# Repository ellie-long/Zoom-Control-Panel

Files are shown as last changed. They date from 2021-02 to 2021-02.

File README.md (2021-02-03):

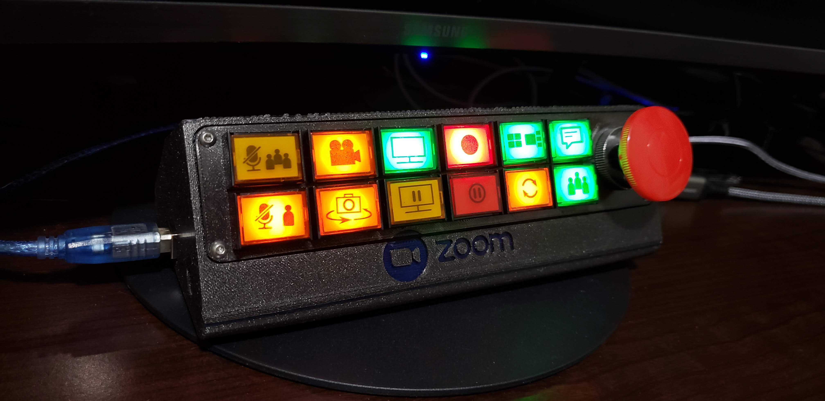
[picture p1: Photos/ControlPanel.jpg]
Zoom Control Panel

# Zoom Control Panel
 A push-button control panel for Zoom
 
 This repo contains files for building a push-button control panel for Zoom. It was made using Windows short cuts, but could easily be modified for Mac instead. 
 
 There are four major components to this build:
 * A 3D-printed case
 * Optional: Printing and installing button icons
 * Wiring buttons and Arduino Mega 2560
 * Programming Arduino
 
# Parts List
 In order to build this project, you will need:
 * Access to a 3D printer
 * An Arduino Mega 2560 board
   * An optional spare Arduino for uploading HoodLoader2 (https://github.com/NicoHood/HoodLoader2), which is required to use the Mega2560 as a keyboard input 
 * A 2560 Prototype Circuit Breakout Board PCB
 * Enough 2.54mm male header pins to mount the breakout board PCB to the Arduino
   * I used the full groupings of 1x10, 5 1x8, 2 1x18 in mine for stability, though you could get away with just the two 1x18 or a single 2x18
 * 12 rectangular LA128A push buttons rated at 12V
   * (If you find 5V ones, even better, though the 12V ones work just fine.) 
   * This design was made with the 16mm rectangular ones in mind, though others should work as well -- however, the button icons may need to be scaled to fit other sizes
   * As designed, I used the following, though you can update it to your own preference:
     * 4 Orange Latching Switches
     * 2 Orange Momentary Switches
     * 2 Red Latching Switches
     * 3 Green Momentary Switches
     * 1 Green Latching Switch
 * A red mushroom LAY37-11ZS push button
 * 13 10k Ohm Resistors
 * Various hook-up wires, preferably in multiple colors to keep track of wires
 * Optional: Glossy transparent printable sticker 'paper' for icons
 * 8 M3 nuts
 * 8 small M3 screws
 * Optional long USB-A or USB extension cable to connect panel to the computer
 * Small flathead screwdriver

# 3D Printed Case
 There are two files that need to be 3D printed to create the case. They are found in 3D Print/To Print, which contains these \*.stl files for the button panel and the main body.
 These files have been designed to not require supports when printing, though you may want to use a brim. I printed it on a Prusa Mk3S+ using PETG with 0.20mm layer heights.
 
 Once printed, M3 nuts can be pushed into place for each of the 8 screw-holes. If they fall out, you can use a small amount of superglue around the edge to hold them into place.
 
 The CAD design was built in FreeCAD, and the original FreeCAD files are included under 3D Print/CAD Files if you wish to modify them.

# Printing and Installing Button Icons
 * In the Icons folder you can find a \*.svg and \*.pdf of icons that can be printed onto transparent sticker 'paper', carefully cut out, and adhered to the push buttons.
 * Using a small flathead screwdriver, you can carefully remove the colored transparent window from the push buttons. 
 * Behind it sits a white rectangle, followed by a white piece of plastic that connects the button mechanism to the front part that is pressed. 
 * Carefully place the sticker onto the white rectangle, then reassemble the button
   * Make sure to check that the button pushes and released properly. If not, the button may have been inserted backwards. 
     * Try to keep track of which buttons each parts came from, as mixing them can lead to buttons sticking.
 * As printed, the buttons are:
   * Mute Me | Video | Share Screen | Record | Gallery/Speaker View | Chat
   * Mute All | Camera | Pause Screen Share | Pause Recording | Reset | Participants

# Wiring and Assembly
* Before spending a lot of time wiring, first make sure to install HoodLoader2 on your Arduino so that you can use it as a keyboard. Follow the Hardware and Software Installations in their wiki before going further: https://github.com/NicoHood/HoodLoader2/wiki/Hardware-Installation
* Install each of the buttons onto the 3D printed Button Panel
  * I found it easiest to have the flat side of the buttons flush against the panel and to install the rubber o-rings on the back side before putting in the square washers and screwing them in place
* Solder the headers onto the PCB board
* For wiring the buttons, follow the wiring diagram in the folder Wiring and solder the buttons . It's provided in \*.pdf, \*.svg, and \*.png formats
  * The resistors can be soldered directly on each button between the negative side of the LED and the 'C' (common) pin of the switch
  * For the 5V-side, make sure that you use the 'NO' (Normally Open) pin of the switch
  * Don't forget to include the 10k Ohm resistor on the mushroom button, and make sure that it's wired to the 'green' side so that the switch is closed when the button is pressed. You can check that it's on the correct side using a multimeter.

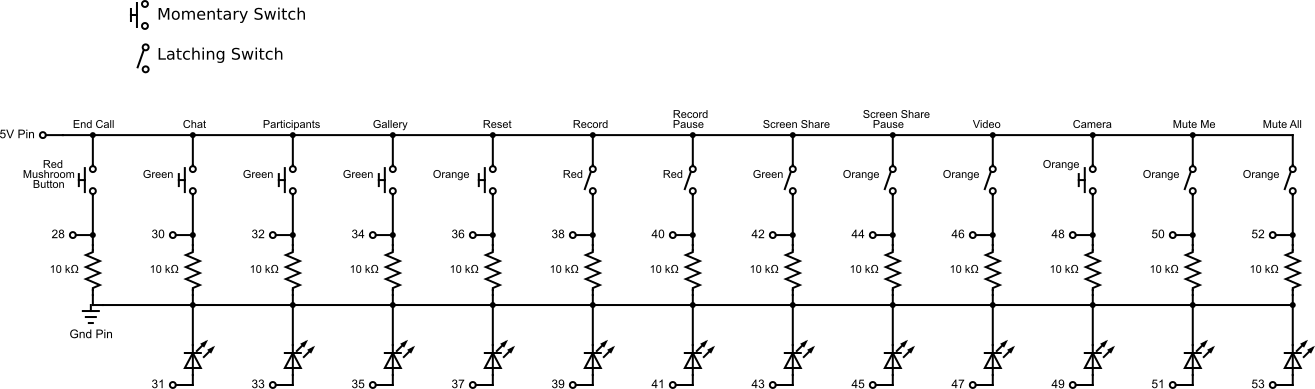
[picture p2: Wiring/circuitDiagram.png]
Wiring Diagram


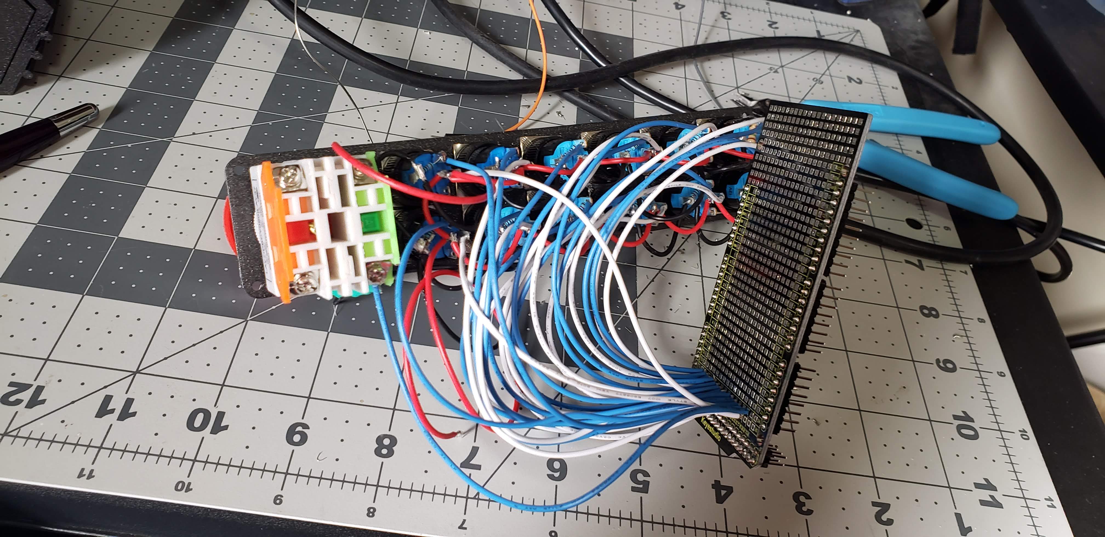
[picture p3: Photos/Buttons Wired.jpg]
Nearly completed wiring

* Once the wiring is complete, attach the PCB to the Arduino and place it inside of the panel. 
* Carefully place the bottom 4 M3 screws into position and screw them in. (if you can only get the front 2 in, that will also work fine)
* Gently push the button panel into place and attach it with the 4 remaining M3 screws. 

# Programming Arduino
* Before programming the Arduino, make sure that you have installed both the Arduino IDE (https://www.arduino.cc/en/software/) and HoodLoader2 on your Arduino so that you can use it as a keyboard. Follow the Hardware and Software Installations in their wiki before going further: https://github.com/NicoHood/HoodLoader2/wiki/Hardware-Installation
  * Hopefully HoodLoader was installed before you finished wiring, or else you'll need to pull the Arduino to install it following the instructions linked above
* The files needed to upload to the Arduino are located in the Arduino folder. There are three:
  * blankIno.ino is a blank Arduino file to upload when switching between the 16u and Mega 2560 chipset. After uploading to the 16u chip, I find uploading this twice to the Mega 2560 the easiest way to regain access to the Mega 2560 chip
  * controlBox.ino is the primary code that should be uploaded to the Mega 2560 chip -- NOT the 16u chip
    * It defines the pins of each button and sends serial commands to the 16u chip using the Serial1 commands
    * Make sure to upload this software each time before uploading HID-Bridge on the 16u.
    * If debugging, you can uncomment the Serial.print(allData) line and run the serial monitor to make sure your buttons are working correctly. This should only be done before uploading the HID-Bridge to the 16u, and make sure to comment that line and re-upload this code before uploading HID-Bridge or else some strange effects may occur by flooding the serial port with text
  * HID-Bridge_USB.ino allows the Arduino Mega 2560 to be used as a keyboard input device. This software can only be loaded if HoodLoader2 is installed, and should be uploaded to the 16u chip -- NOT the Mega 2560 chip
* Once the software is uploaded, you should be able to use your new Zoom Control Panel! If you run into issues, you can use the on-screen keyboard to make sure that the modifier keys are being input correctly, or open a Zoom channel to test out your new control box.
  * Note: The 'Reset' button currently toggles the momentary switch LEDs so that you can leave the box plugged in without having the LEDs lit up. 

# Attributions
This project was inspired by https://github.com/lanewinfield/zoomout and https://www.instructables.com/Zoom-Control-Box/, and would not have been possible to finish using the Arduinos I had sitting around if not for https://github.com/NicoHood/HoodLoader2/

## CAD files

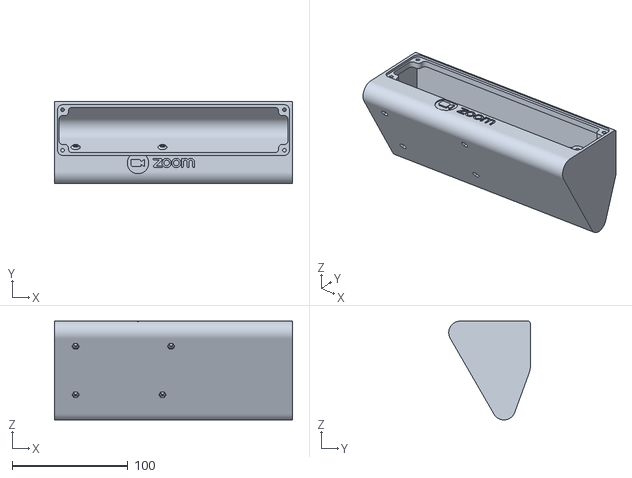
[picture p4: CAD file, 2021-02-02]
3D Print/To Print/Zoom - Main Body.stl
206.0 x 70.6 x 85.5

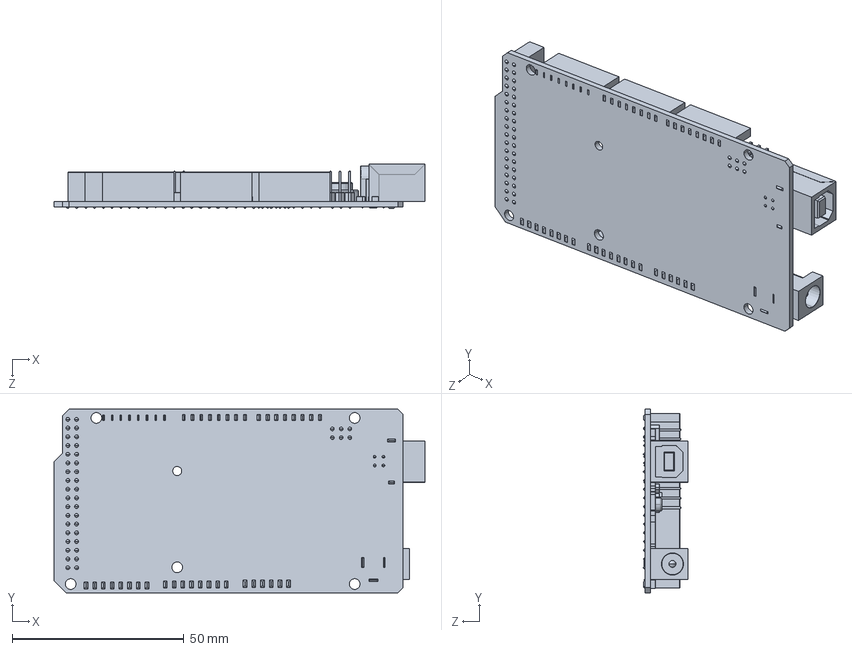
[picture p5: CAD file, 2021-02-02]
3D Print/CAD Files/ArduinoMega_STEP_AP203.STEP
107.9 x 53.4 x 13.0 mm

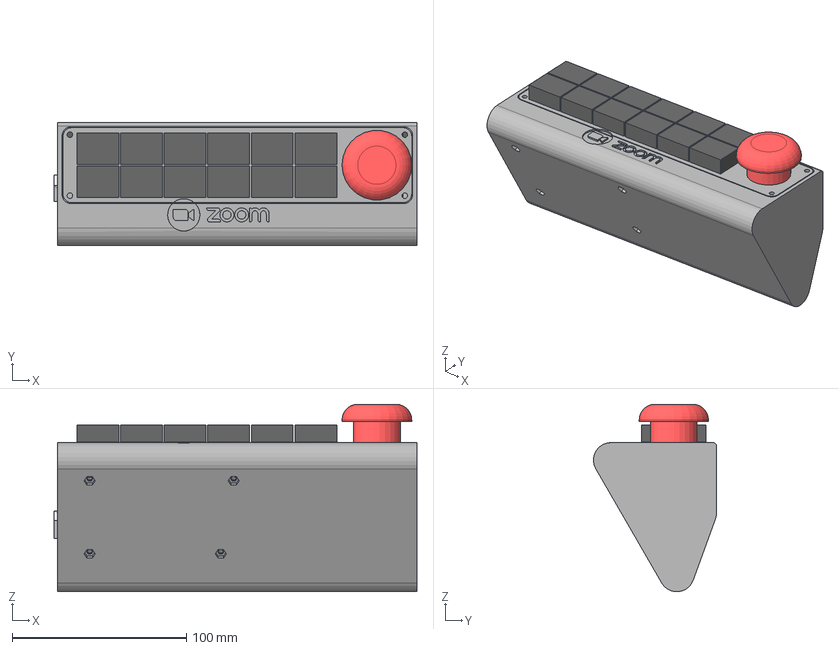
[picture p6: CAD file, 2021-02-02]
3D Print/CAD Files/Zoom Control Box.FCStd
208.1 x 70.6 x 107.5 mm
ArduinoMega_STEP_AP203
LA128A Push Buttons
PBCY090 Button
Button Panel
Main Body003

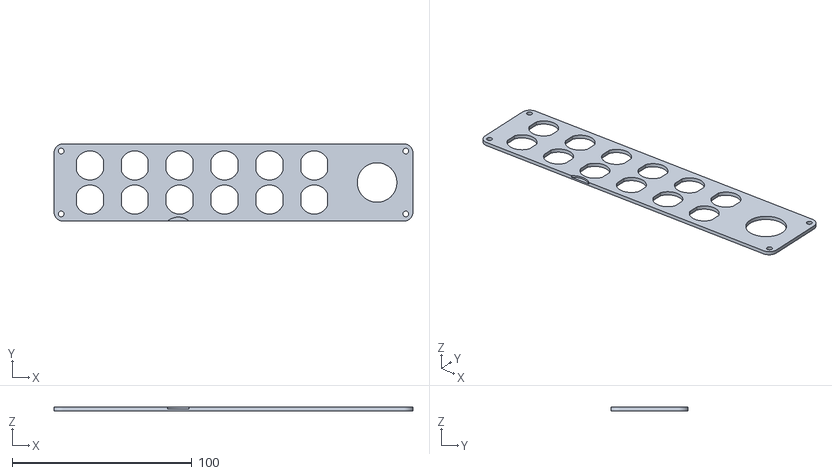
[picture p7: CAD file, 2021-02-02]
3D Print/To Print/Zoom - Button Panel.stl
200.0 x 43.0 x 2.00

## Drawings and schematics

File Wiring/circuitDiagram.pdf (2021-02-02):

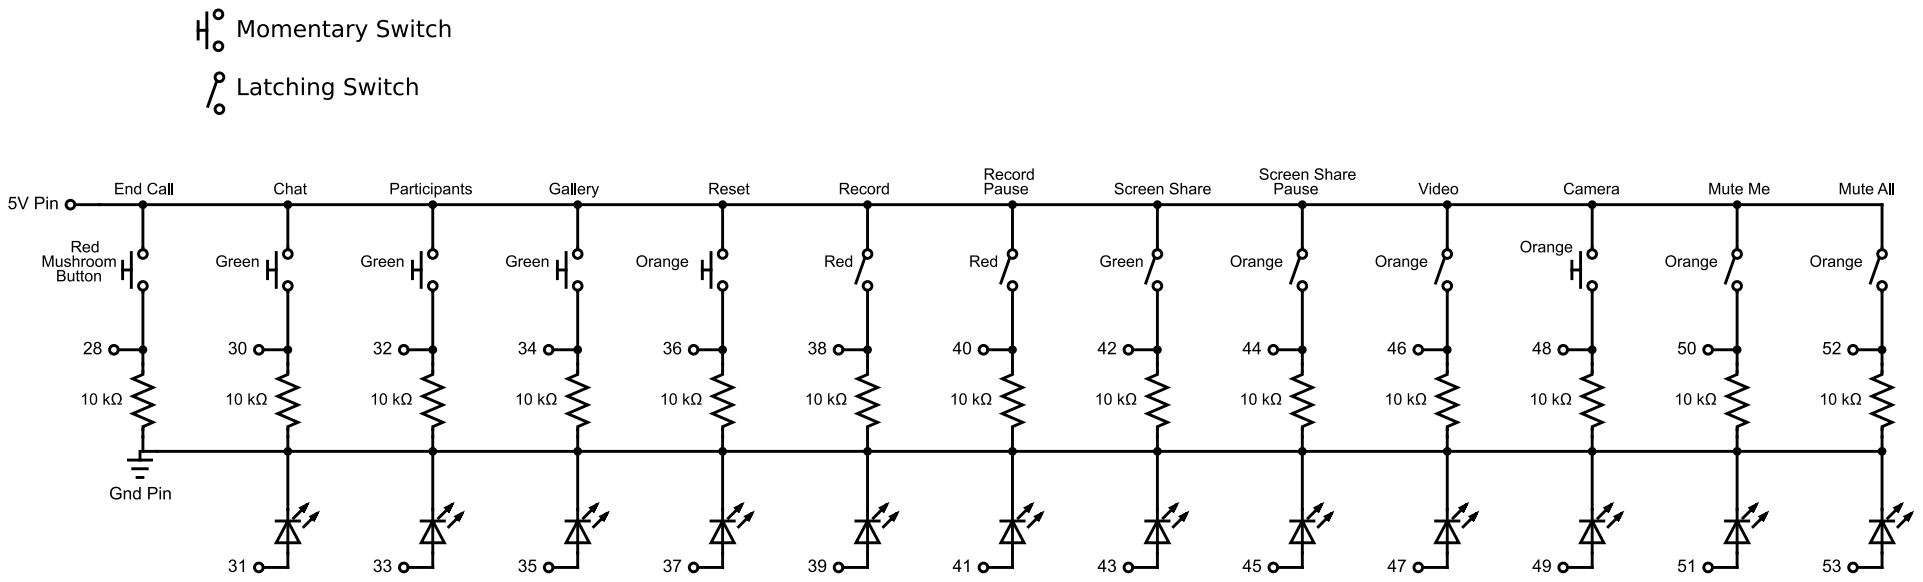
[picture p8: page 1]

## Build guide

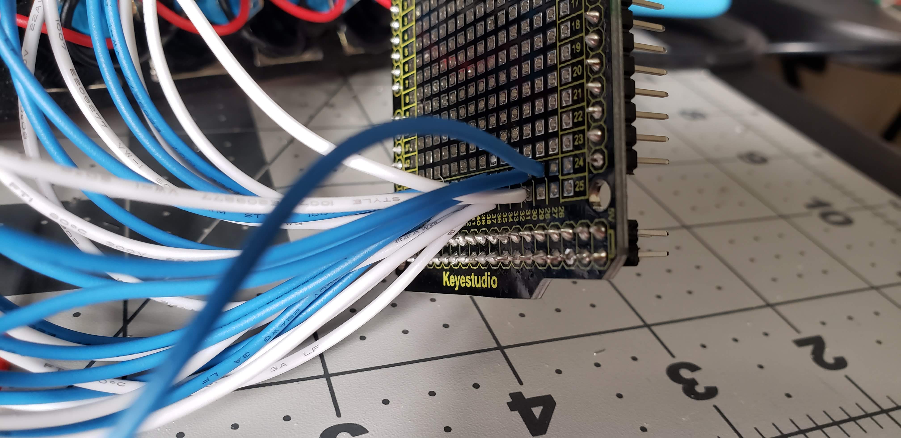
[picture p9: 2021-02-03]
Photos/PCB Wiring.jpg

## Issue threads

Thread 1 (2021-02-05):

README, where to purchase switches

paulywill, 2021-02-05:
I really like the buttons recommended.

Where do you recommend to purchase?

ellie-long, 2021-02-05:
I had picked them up a long time ago on Amazon for a KSP controller that never got built. I think it was these in various colors, some latching, some momentary: https://www.amazon.com/gp/product/B01N6FZZ0E/ref=ppx_yo_dt_b_asin_title_o01_s00?ie=UTF8&psc=1

And this for the mushroom, removed from the box it came in: https://www.amazon.com/URBEST-Momentary-Mushroom-Position-Rotary/dp/B01M0K8XY6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

paulywill, 2021-02-08:
Amazing!

And those awesome icons? Are they "in" the button? How did you get or generate those?

Thanks for answering this BTW! Much appreciated!!

ellie-long, 2021-02-08:
The icons are in the github -- I printed them on sticker paper and attached them on the buttons under the colored plastic bits

Closed 2021-02-08.

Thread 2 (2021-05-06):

Should I change anything in HID-bridge_USB?

albanrr9, 2021-05-06:
Hi,
I'm adding a rotary encoder to control PC Volume.
Should I add or remove anything in HID-bridge_USB.ino?
And another question,
Did I write correctly the new controlBox.ino?
I wrote it by combining your controlBox.ino and VolumeCtrl.ino from https://www.instructables.com/USB-Volume-Control-and-Caps-Lock-LED-Simple-Cheap-/  .
I'm not going to make this project with any LED so I removed pieces of code for LED.

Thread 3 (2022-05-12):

CAD files

paulywill, 2022-05-12:
@ellie-long, would love to learn more about the design of the 3d print.

What software did you use to make the CAD and STL files?
Is there anything you would recommend for those starting to learn about design and ideal goals for intermediate to pro levels?

ellie-long, 2022-08-11:
I used FreeCAD to design it. Every CAD software has their own quirks, so I'd recommend choosing one you think will meet your needs and trying to stick with it, as though many pieces of software can do similar things, they often go about it in different ways. A great way for learning about design and ideas is to peruse files available on 3D printing sites and learning how to edit them -- it gives you a good starting sense of how things get put together.

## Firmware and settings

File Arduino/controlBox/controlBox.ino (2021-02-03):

const int offBtn = 28;
const int chatBtn = 30;
const int partBtn = 32;
const int galleryBtn = 34;
const int resetBtn = 36;
const int recordBtn = 38;
const int recPauseBtn = 40;
const int screenBtn = 42;
const int scPauseBtn = 44;
const int videoBtn = 46;
const int cameraBtn = 48;
const int muteMeBtn = 50;
const int muteAllBtn = 52;

const int chatLED = 31;
const int partLED = 33;
const int galleryLED = 35;
const int resetLED = 37;
const int recordLED = 39;
const int recPauseLED = 41;
const int screenLED = 43;
const int scPauseLED = 45;
const int videoLED = 47;
const int cameraLED = 49;
const int muteMeLED = 51;
const int muteAllLED = 53;

int muteMeState = 0;
int muteAllState = 0;
int videoState = 0;
int camState = 0;
int screenState = 0;
int scPauseState = 0;
int recordState = 0;
int recPauseState = 0;
int galleryState = 0;
int resetState = 0;
int chatState = 0;
int partState = 0;
int offState = 0;
int boxReset = 0;

int lastMuteMe = 0;
int lastMuteAll = 0;
int lastVideo = 0;
int lastScreen = 0;
int lastScPause = 0;
int lastRecord = 0;
int lastRecPause = 0;

String offStr = "";
String muteMeStr = "";
String muteAllStr = "";
String videoStr = "";
String camStr = "";
String screenStr = "";
String scPauseStr = "";
String recStr = "";
String recPauseStr = "";
String galleryStr = "";
String chatStr = "";
String resetStr = "";
String partStr = "";
String newData = "-------------------------------------\n";
String allData = "";

int stateChange = 1;
int firstRun = 1;

int delayTime = 500;
void setup()
{
  // Buttons
  pinMode(offBtn, INPUT);
  pinMode(chatBtn, INPUT);
  pinMode(partBtn, INPUT);
  pinMode(galleryBtn, INPUT);
  pinMode(resetBtn, INPUT);
  pinMode(recordBtn, INPUT);
  pinMode(recPauseBtn, INPUT);
  pinMode(screenBtn, INPUT);
  pinMode(scPauseBtn, INPUT);
  pinMode(videoBtn, INPUT);
  pinMode(cameraBtn, INPUT);
  pinMode(muteMeBtn, INPUT);
  pinMode(muteAllBtn, INPUT);
  // LEDs
  pinMode(chatLED, OUTPUT);
  pinMode(partLED, OUTPUT);
  pinMode(galleryLED, OUTPUT);
  pinMode(resetLED, OUTPUT);
  pinMode(recordLED, OUTPUT);
  pinMode(recPauseLED, OUTPUT);
  pinMode(screenLED, OUTPUT);
  pinMode(scPauseLED, OUTPUT);
  pinMode(videoLED, OUTPUT);
  pinMode(cameraLED, OUTPUT);
  pinMode(muteMeLED, OUTPUT);
  pinMode(muteAllLED, OUTPUT);
  Serial.begin(115200);

}

void loop()
{
  if (firstRun == 1){
    digitalWrite(chatLED, HIGH);
    digitalWrite(partLED, HIGH);
    digitalWrite(galleryLED, HIGH);
    digitalWrite(resetLED, HIGH);
    digitalWrite(cameraLED, HIGH);
    firstRun = 0;
    boxReset = 1;
  }
  
  // Momentary Buttons
  offState = digitalRead(offBtn);
  camState = digitalRead(cameraBtn);
  galleryState = digitalRead(galleryBtn);
  resetState = digitalRead(resetBtn);
  chatState = digitalRead(chatBtn);
  partState = digitalRead(partBtn);

  if (offState == HIGH){
    stateChange = 1;
    Serial.write('q');
    delay(delayTime);
  }
  if (camState == HIGH){
    stateChange = 1;
    Serial.write('n');
    delay(delayTime);
  }
  if (galleryState == HIGH){
    stateChange = 1;
    Serial.write('g');
    delay(delayTime);
  }
//  if (resetState == HIGH){
//    Serial.write('r');
//    delay(delayTime);
//  }
  if (chatState == HIGH){
    stateChange = 1;
    Serial.write('h');
    delay(delayTime);
  }
  if (partState == HIGH){
    stateChange = 1;
    Serial.write('u');
    delay(delayTime);
  }
  if (resetState == HIGH){
    stateChange = 1;
    if (boxReset == 0){
      digitalWrite(chatLED, HIGH);
      digitalWrite(partLED, HIGH);
      digitalWrite(galleryLED, HIGH);
      digitalWrite(resetLED, HIGH);
      digitalWrite(cameraLED, HIGH);
      boxReset = 1;
    }
    else if (boxReset == 1){
      digitalWrite(chatLED, LOW);
      digitalWrite(partLED, LOW);
      digitalWrite(galleryLED, LOW);
      digitalWrite(resetLED, LOW);
      digitalWrite(cameraLED, LOW);
      boxReset = 0;    
    }
//    Serial.write('q');
    delay(delayTime);
  }

  // Latching Buttons
  muteMeState = digitalRead(muteMeBtn);
  if (muteMeBtn == HIGH){
    muteMeState = 1;
  }
  else{
    muteMeState = 0;
  }
  if (muteMeState != lastMuteMe){
    stateChange = 1;
    if (muteMeState == 1)
    {
      digitalWrite(muteMeLED, HIGH);
      lastMuteMe = 1;
      Serial.write('a');
    } 
    else if (muteMeState == 0){
      digitalWrite(muteMeLED, LOW);
      lastMuteMe = 0;
      Serial.write('a');
    }
  }

  muteAllState = digitalRead(muteAllBtn);
  if (muteAllState != lastMuteAll){
    stateChange = 1;
    if (muteAllState == HIGH)
    {
      digitalWrite(muteAllLED, HIGH);
      lastMuteAll = 1;
      Serial.write('m');
//      Serial.write('a');
    } 
    else{
      digitalWrite(muteAllLED, LOW);
      lastMuteAll = 0;
      Serial.write('m');
//      Serial.write('a');
    }  
  }
  
  
  videoState = digitalRead(videoBtn);
  if (videoState != lastVideo){
    stateChange = 1;
    if (videoState == HIGH)
    {
      digitalWrite(videoLED, HIGH);
      lastVideo = 1;
      Serial.write('v');
    } 
    else{
      digitalWrite(videoLED, LOW);
      lastVideo = 0;
      Serial.write('v');
    }
  }


  screenState = digitalRead(screenBtn);
  if (screenState != lastScreen){
    stateChange = 1;
    if (screenState == HIGH)
    {
      digitalWrite(screenLED, HIGH);
      lastScreen = HIGH;
      Serial.write('s');
    } 
    else{
      digitalWrite(screenLED, LOW);
      lastScreen = 0;
      Serial.write('s');
    }
  }

  
  scPauseState = digitalRead(scPauseBtn);
  if (scPauseState != lastScPause){
    stateChange = 1;
    if (scPauseState == HIGH)
    {
      digitalWrite(scPauseLED, HIGH);
      lastScPause = 1;
      Serial.write('t');
    } 
    else if (scPauseState == LOW){
      digitalWrite(scPauseLED, LOW);
      lastScPause = 0;
      Serial.write('t');
    }
  }
  
  recordState = digitalRead(recordBtn);
  if (recordState != lastRecord){
    stateChange = 1;
    if (recordState == HIGH)
    {
      digitalWrite(recordLED, HIGH);
      lastRecord = 1;
      Serial.write('c');
    } 
    else{
      digitalWrite(recordLED, LOW);
      lastRecord = 0;
      Serial.write('c');
    }    
  }

  recPauseState = digitalRead(recPauseBtn);
  if (recPauseState != lastRecPause){
    stateChange = 1;
    if (recPauseState == HIGH)
    {
      digitalWrite(recPauseLED, HIGH);
      lastRecPause = 1;
      Serial.write('p');
    } 
    else{
      digitalWrite(recPauseLED, LOW);
      lastRecPause = 0;
      Serial.write('p');
    }   
  }

  if (stateChange == 1){
    offStr = "OFF = " + String(offState) + "\n";
    muteMeStr = "MUTEME = " + String(muteMeState) + "\n";
    muteAllStr = "MUTEALL = " + String(muteAllState) + "\n";
    videoStr = "VIDEO = " + String(videoState) + "\n";
    camStr = "CAMERA = " + String(camState) + "\n";
    screenStr = "SCREEN = " + String(screenState) + "\n";
    scPauseStr = "SCPAUSE = " + String(scPauseState) + "\n";
    recStr = "RECORD = " + String(recordState) + "\n";
    recPauseStr = "RECPAUSE = " + String(recPauseState) + "\n";
    galleryStr = "GALLERY = " + String(galleryState) + "\n";
    chatStr = "CHAT = " + String(chatState) + "\n";
    resetStr = "RESET = " + String(resetState) + "\n";
    partStr = "PART = " + String(partState) + "\n";
    allData = offStr + muteMeStr + muteAllStr + videoStr + camStr + screenStr + scPauseStr + recStr + recPauseStr + galleryStr + chatStr + resetStr + partStr + newData;    
//    Serial.print(allData);
    stateChange = 0; 
    delay(delayTime);
  }

  
  
  
  
  
}

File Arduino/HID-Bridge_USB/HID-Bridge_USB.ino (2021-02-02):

/*hyx
 Copyright (c) 2014-2015 NicoHood
 See the readme for credit to other people.

 Serial HID-Bridge USB
 Select HoodLoader16u2 as board.

 After upload make sure the 16u2 sketch runs, not the HoodLoader2 bootloader.
 This example will type any serial data via keyboard.
*/

#include "Keyboard.h"
#include "HID.h"
char ctrlKey = KEY_LEFT_CTRL;
char altKey = KEY_LEFT_ALT;
char shiftKey = KEY_LEFT_SHIFT;
char returnKey = KEY_RETURN;
char f1Key = KEY_F1;
char f2Key = KEY_F2;
int gState = 0;
int delayTime = 150;


void setup() {
  // Start the Serial1 which is connected with the IO MCU.
  // Make sure both baud rates are the same
  // you can go up to 2000000 for very fast data transmission.
  Serial1.begin(115200);

  // Sends a clean report to the host. This is important on any Arduino type.
  Keyboard.begin();

  // Start the USB Serial for debugging
  Serial.begin(115200);
}

void loop() {
  // Check if any Serial data from the IO MCU was received
  char c = Serial1.read();
  if (c>0){
    Serial.print(c);
  }
//  Serial.print(c);

//  // If it's a character, print it!
//  if (c >= 'a' && c <= 'z') {
////    Serial.print(F("USB: "));
//    Serial.print(c);
//    Serial.print('\n');
////    Keyboard.print(c);
//  }

  if (c== 'a' or c=='m' or c=='v' or c=='s' or c=='t' or c=='c' or c=='p' or c=='n' or c=='q' or c=='h' or c=='u'){
    Keyboard.press(ctrlKey);
    Keyboard.press(altKey);
    Keyboard.press(shiftKey);
    delay(delayTime);
    Keyboard.releaseAll();
    Serial.print("USB: ALT+");
    Serial.print(c);
    Serial.print('\n');
    Keyboard.press(altKey);
    Keyboard.press(c);
    delay(delayTime);
    Keyboard.releaseAll();
    if (c=='q'){
      Keyboard.press(returnKey);
      delay(delayTime);
      Keyboard.releaseAll();
    }
  }

  if (c== 'g'){
    if (gState==0){
      Keyboard.press(ctrlKey);
      Keyboard.press(altKey);
      Keyboard.press(shiftKey);
      delay(delayTime);
      Keyboard.releaseAll();
      Serial.print("USB: ALT+F1");
      Serial.print('\n');
      Keyboard.press(altKey);
      Keyboard.press(f1Key);
      delay(delayTime);
      Keyboard.releaseAll();
      gState =1;
    }
    else if (gState==1){
      Keyboard.press(ctrlKey);
      Keyboard.press(altKey);
      Keyboard.press(shiftKey);
      delay(delayTime);
      Keyboard.releaseAll();
      Serial.print("USB: ALT+F2");
      Serial.print('\n');
      Keyboard.press(altKey);
      Keyboard.press(f2Key);
      delay(delayTime);
      Keyboard.releaseAll();
      gState =0;
    }
  }

}

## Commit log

2021-02-02 First commit
    First Commit
    [ArduinoMega_STEP_AP203.STEP, Zoom - Button Panel.stl, Zoom - Main Body.stl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]
2021-02-02 moved 3D printing files to better folder structure
    [ArduinoMega_STEP_AP203.STEP, Zoom - Button Panel.stl, Zoom - Main Body.stl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]
2021-02-02 Added 3d printing instructions
2021-02-02 Starting 'wiring' section
2021-02-02 Added circuit diagrams for wiring
2021-02-03 working on wiring section
2021-02-03 Added Programming Arduino section
